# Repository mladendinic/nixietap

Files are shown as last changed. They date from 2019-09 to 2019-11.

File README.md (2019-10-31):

Hello!

You have stumbled upon a repository which contains files for the Nixie Tap device.

What is a Nixie Tap? It's an ESP8266-based Nixie display in a nice enclosure.

By default, it's an internet-synchronized clock, but it could be whatever you desire: IFTTT button, cryptocurrency price ticker, temperature alarm...

To build the latest hardware, use the files from the hardware folder, buy the parts and PCBs, and fire up the soldering iron.

To build the latest firmware, open the 'firmware' repo in VS Code / Github Atom with PlatformIO, and download it to the ESP from there.

There is also a website with more details, here: https://mladendinic.com/nixietap/

Have a nice day!

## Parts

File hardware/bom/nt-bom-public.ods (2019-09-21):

NIXIE TAP REV A BOM
Last modified: 21.09.2019.
Description | Manufacturer 1 | Manufacturer Part Number 1 | Supplier 1 | Supplier Part Number 1 | Quantity
Nixie Tube | NOS | IN-12B | Ebay |  | 4
5K1 1% 0805 | YAGEO | RC0805FR-075K1L | LCSC | C84375 | 1
100K 0805 | YAGEO | RC0805FR-07100KL | LCSC | C96346 | 2
820K 1% 0805 | YAGEO | RC0805JR-07820KL | LCSC | C137403 | 2
10K 0805 | YAGEO | RC0805FR-0710KL | LCSC | C84376 | 9
22K 0805 | YAGEO | RC0805FR-0722KL | LCSC | C114565 | 9
Header, 2 Pin, female | Shenzhen Cankemeng |  | LCSC | C124375 | 1
470pF 50V X7R 10% | YAGEO | CC0805KRX7R9BB471 | LCSC | C107152 | 1
470R 0805 | YAGEO | RC0805FR-07470RL | LCSC | C114564 | 6
SMD Pushbutton 4.5x4.5x7mm | BRIGHT | TSA453G80-250 | LCSC | C294498 | 1
Header, 2 Pin, 90 | Shenzhen Cankemeng |  | LCSC | C124411 | 1
100n 0805 50V | YAGEO | CC0805ZRY5V9BB104 | LCSC | C111496 | 12
Diodes - ESD SOT-23-6 RoHS | STMicroelectronics | USBLC6-2SC6 | LCSC | C7519 | 1
10u 0805 25V | Samsung | CL21A106KAYNNNE | LCSC | C15850 | 4
IC 8BIT SHIFT REG 3ST-OUT 16SOIC | ON Semiconductor | MC74HC595ADR2G | LCSC | C7344 | 1
MLCC - SMD/SMT 500volts .047uF X7R 10% | TDK | C3216X7T2J473KT000N | LCSC | C338056 | 1
Touch Screen Controller ICs SOT-23-6 | Tontek Design Tech | TTP223E-BA6 | LCSC | C129457 | 1
HRO USB micro female vertical TH | Korean Hroparts Elec | U-D-M5DD-W-1 | LCSC | C145795 | 1
XTAL, 12.000MHZ, 16PF, SMD, HC-49S | TXC Corp | 9C12000001 | LCSC | C97206 | 1
MOSFET MOSFT 30V 2.7A 100mOhm 1.0nC | International Rectifier | IRLML2030TRPBF | LCSC | IRLML2030TRPBF | 1
18p 0805 50V | AVX | 08055A180J4T2A | LCSC | C273673 | 3
NCP1117, NCV1117. 1.0 A Low-Dropout Positive | On Semiconductor | NCP1117ST33T3G | LCSC | C26537 | 1
MC306 32.768000KHZ 12.5PF | Seiko Epson | Q13MC3061000300 | LCSC | C16320 | 1
Asynchronous Boost Controller | Feeling Technology | FP5139BWR-LF | LCSC | C88318 | 1
CH340G USB to serial (UART) bridge | Jiangsu Qin Heng | CH340G | LCSC | C14267 | 1
Header, 10 Pin, female | Boom Precision Elec |  | LCSC | C35445 | 7
Header, 10 Pin | Shenzhen Cankemeng |  | LCSC | C124372 | 7
ESP-12F Wi-Fi Module by AI-Thinker | Ai-Thinker | ESP-12F(ESP8266MOD) | LCSC or VITA ELKO | C82891 | 1
1.0 A 600V Ultra Fast Recovery Rectifier | ON Semiconductor / Fairchild | ES1J | LCSC | 512-ES1J | 1
NPN High Voltage Transistor | ON Semiconductor | MMBTA42LT1G | Mouser | 863-MMBTA42LT1G | 6
0.04mm gapped core E13/7/4 N27 LP 0.04MM | EPCOS / TDK | B66305G0040X127 | Mouser | 871-B66305G0040X127 | 2
Bobbin for E13/7/4 ferrite core | EPCOS / TDK | B66306C1010T001 | Mouser | 871-B66306C1010T001 | 1
IC RTC CLK/CALENDAR I2C 8-SOIC | Texas Instruments | BQ32000DR | Mouser | 595-BQ32000DR | 1
Supercap, SMD, 0.2F | Elna | DSK-3R3H224U-HL | Mouser | 555-DSK3R3H224U-HL | 1
IC DISPLAY DVR 20CH 80V 28SOIC | Microchip Technology | HV5812WG-G | Mouser | 689-HV5812WG-G | 2
Header, 10 Pin, female, stackable, 3d model only | CONNFLY | DS1023-05-1*10B8-A16.0/B6.8 | TME | DS1023-05-1X10B816 | 2
PCB |  |  |  |  | 1
PCB | LCSC |  |  |  | 1
PCB |  |  |  |  | 1
PCB | JLCPCB |  |  |  | 1
Nixie pins 50 pack @ 1000pcs |  |  |  |  | 1

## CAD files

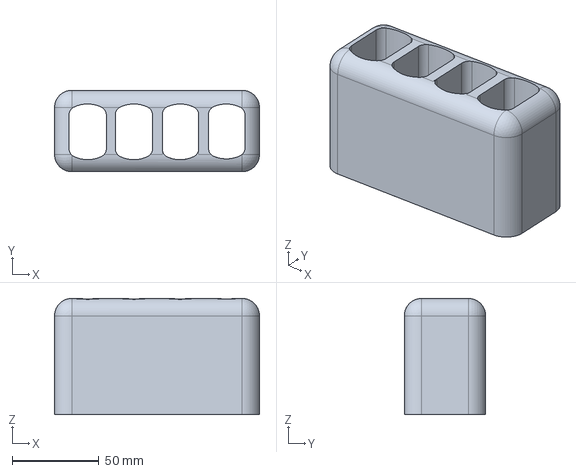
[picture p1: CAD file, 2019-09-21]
hardware/enclosure/nt-enclosure-rev-a.step
118.3 x 47.0 x 67.0 mm

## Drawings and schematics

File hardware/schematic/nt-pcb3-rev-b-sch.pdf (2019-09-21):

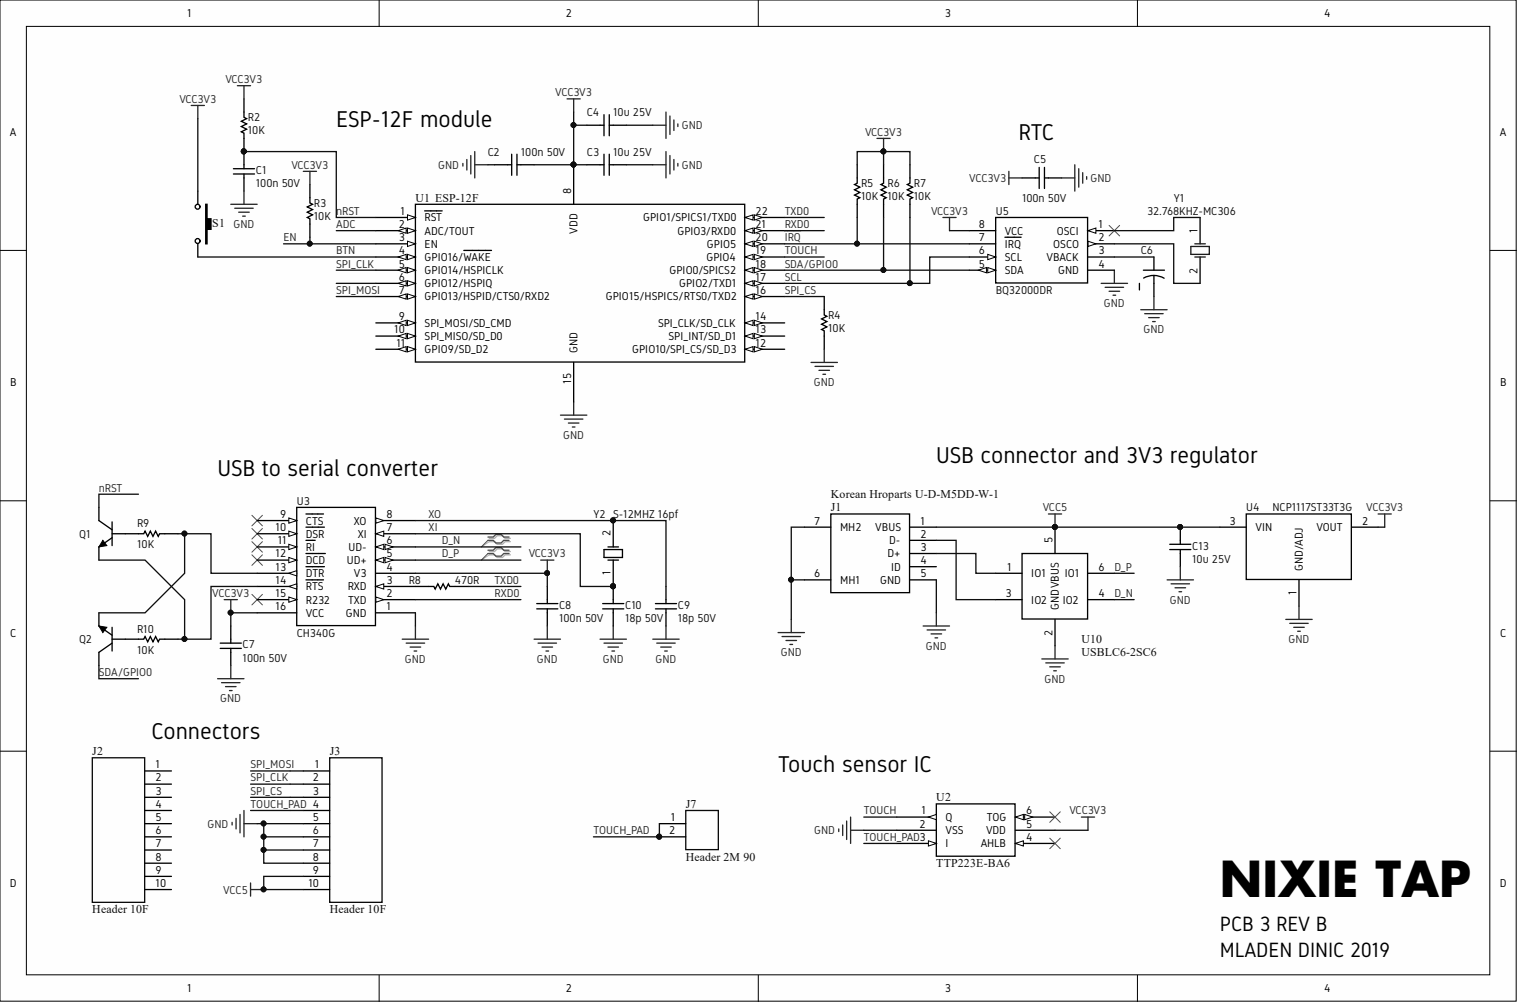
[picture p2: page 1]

GPIO14/HSPICLK 5 GPIO12/HSPIQ 6 GPIO13/HSPID/CTS0/RXD2 7 SPI_MOSI/SD_CMD 9 | SDA/GPIO0

SCL

USB connector and 3V3 regulator USB to serial converter

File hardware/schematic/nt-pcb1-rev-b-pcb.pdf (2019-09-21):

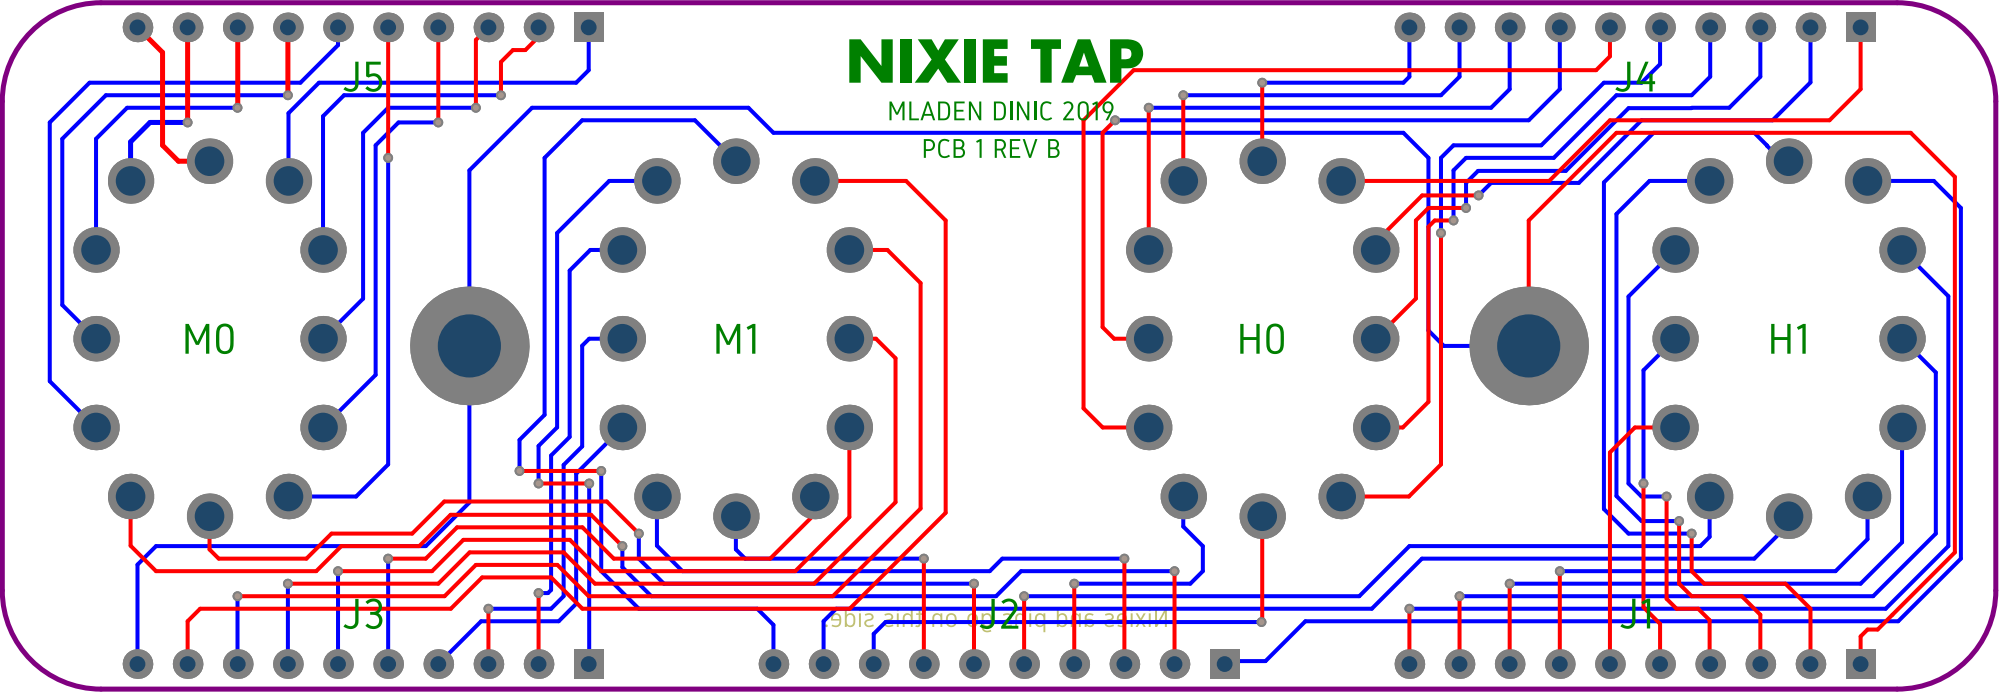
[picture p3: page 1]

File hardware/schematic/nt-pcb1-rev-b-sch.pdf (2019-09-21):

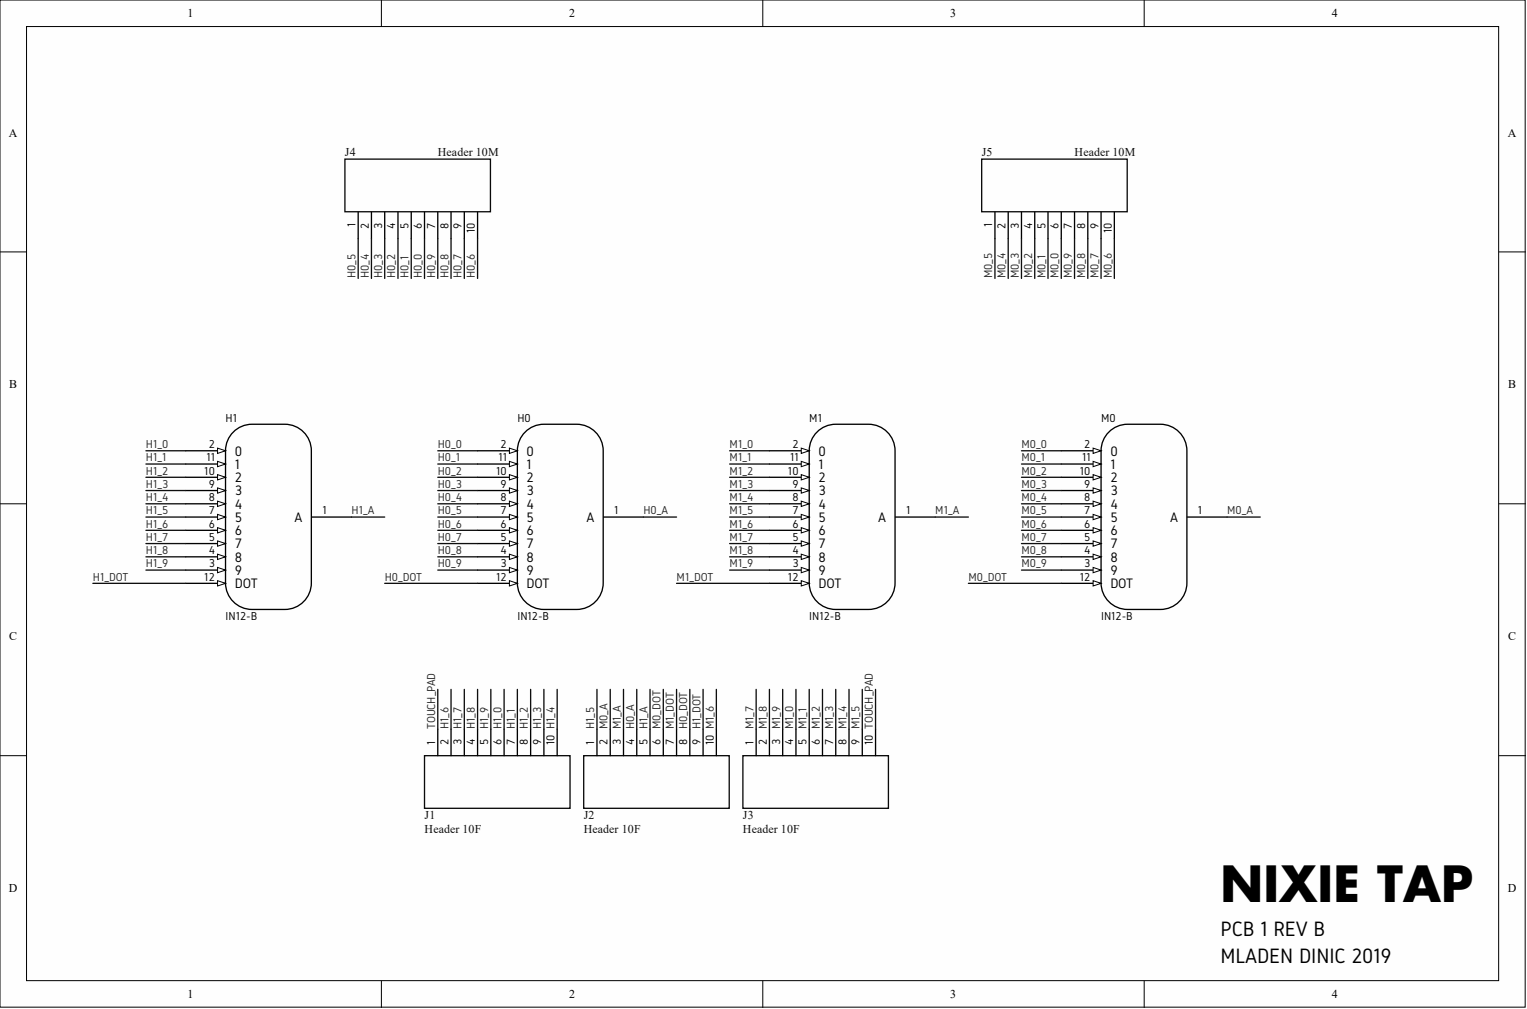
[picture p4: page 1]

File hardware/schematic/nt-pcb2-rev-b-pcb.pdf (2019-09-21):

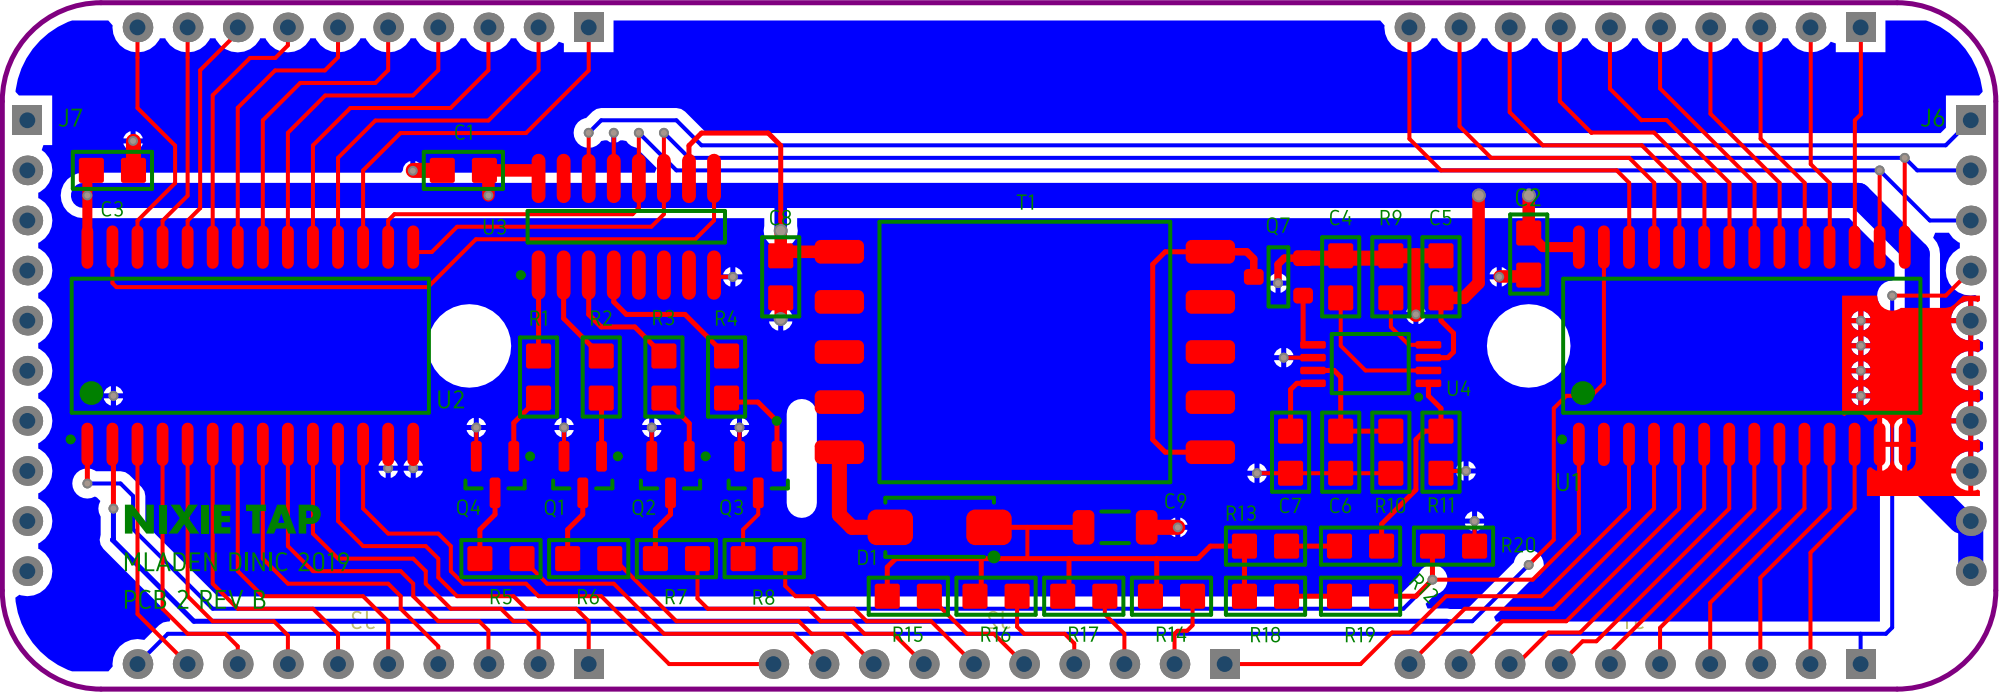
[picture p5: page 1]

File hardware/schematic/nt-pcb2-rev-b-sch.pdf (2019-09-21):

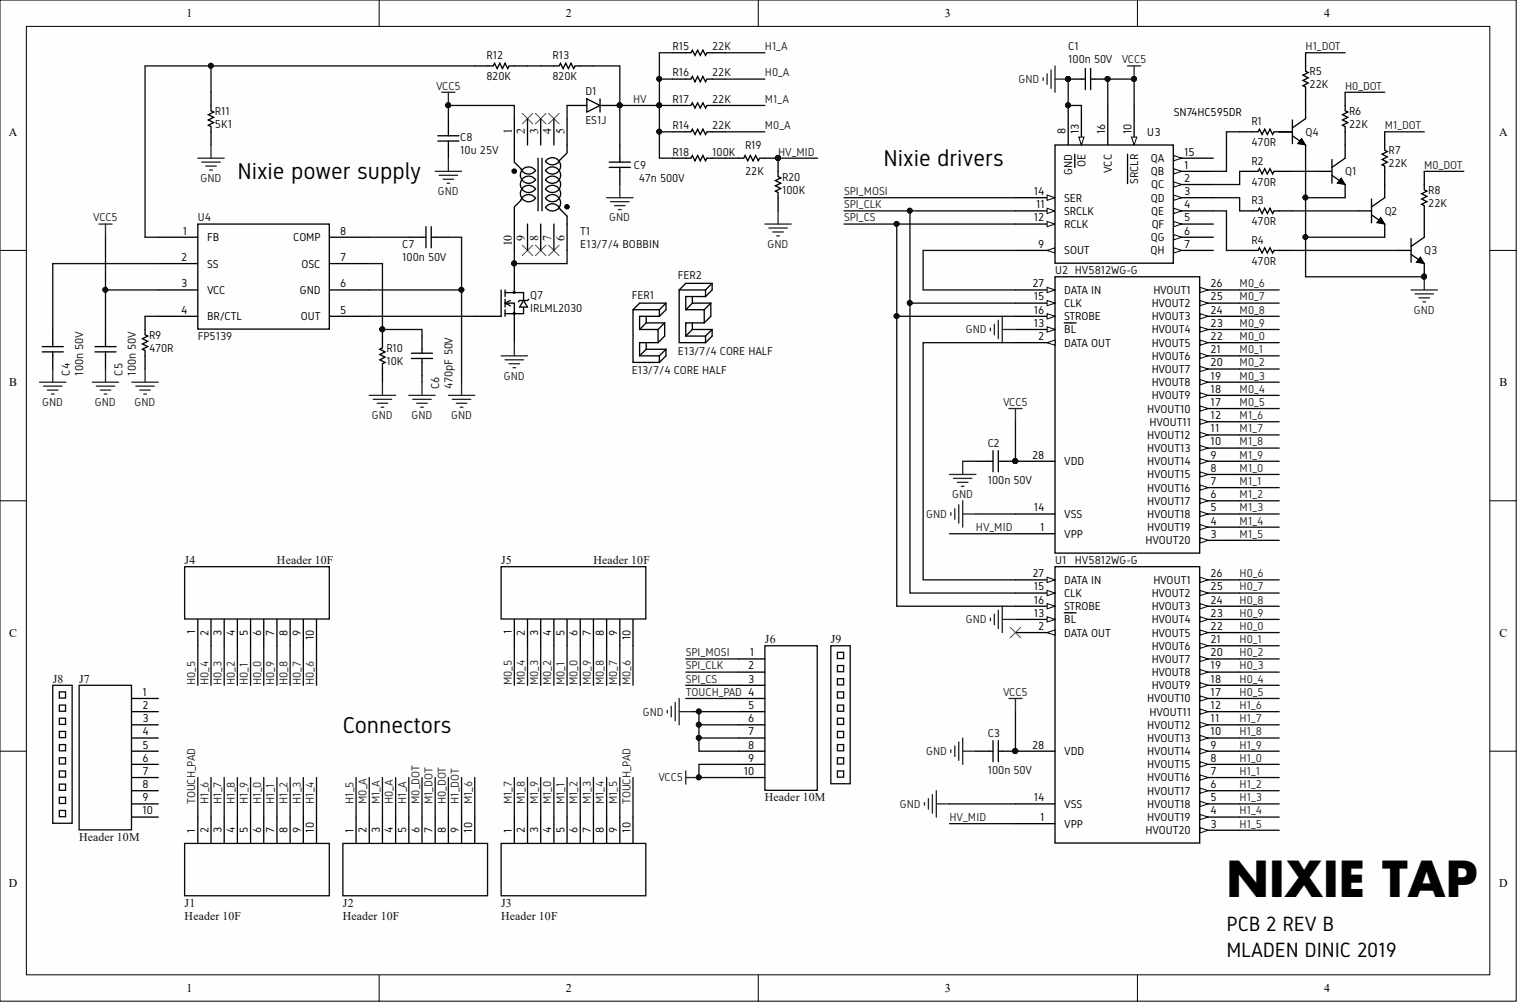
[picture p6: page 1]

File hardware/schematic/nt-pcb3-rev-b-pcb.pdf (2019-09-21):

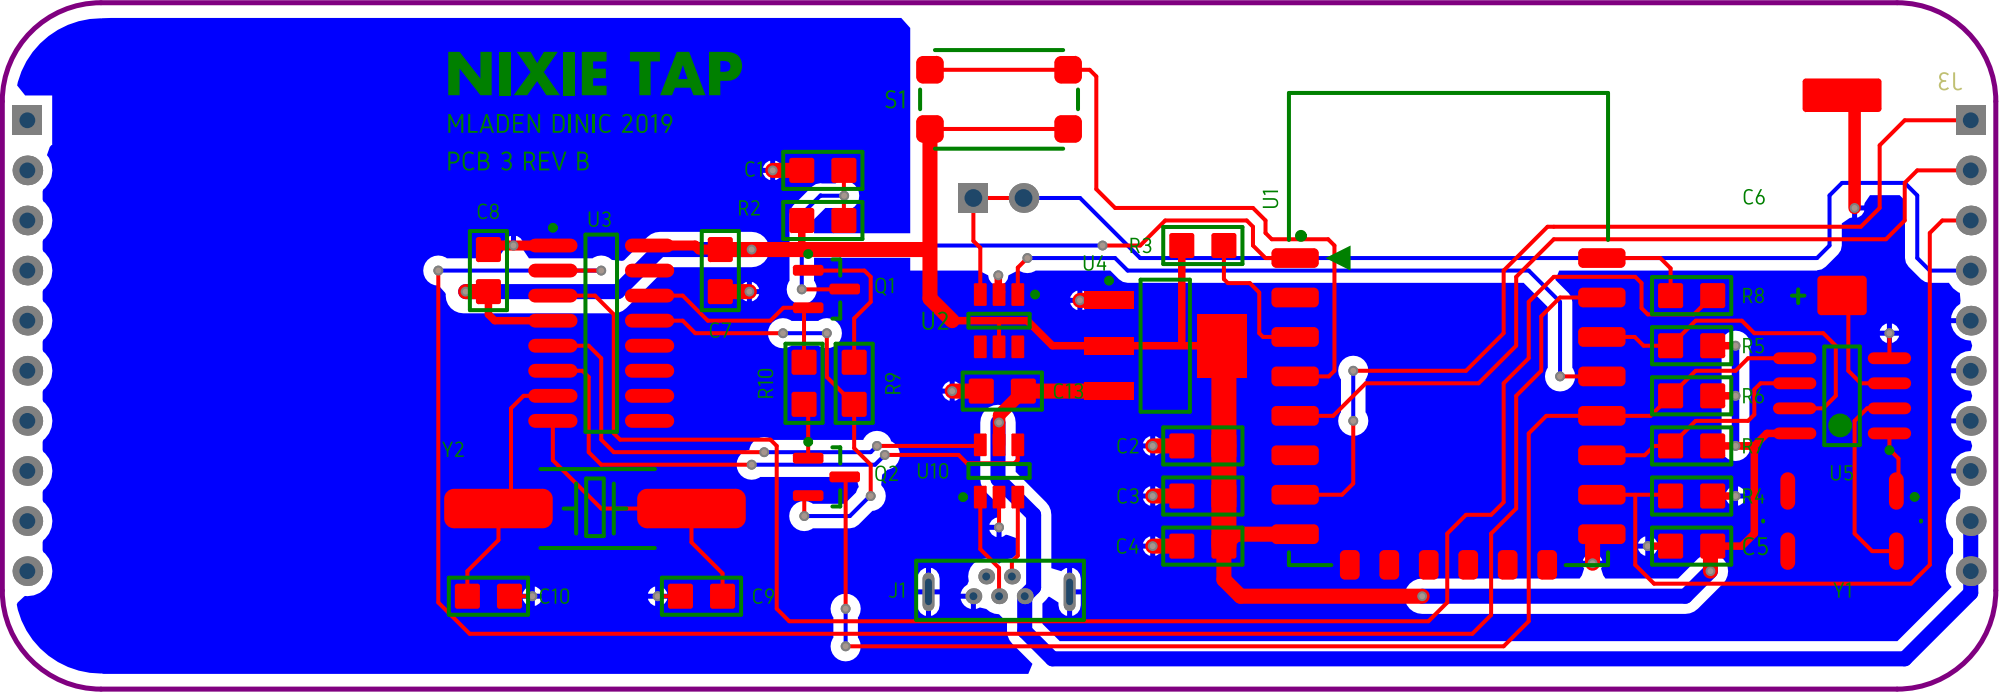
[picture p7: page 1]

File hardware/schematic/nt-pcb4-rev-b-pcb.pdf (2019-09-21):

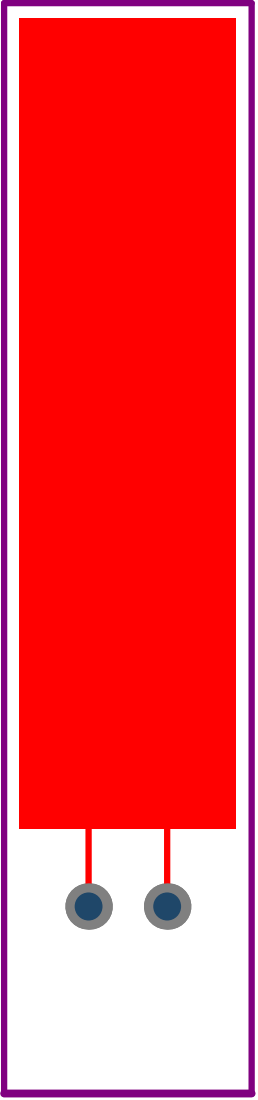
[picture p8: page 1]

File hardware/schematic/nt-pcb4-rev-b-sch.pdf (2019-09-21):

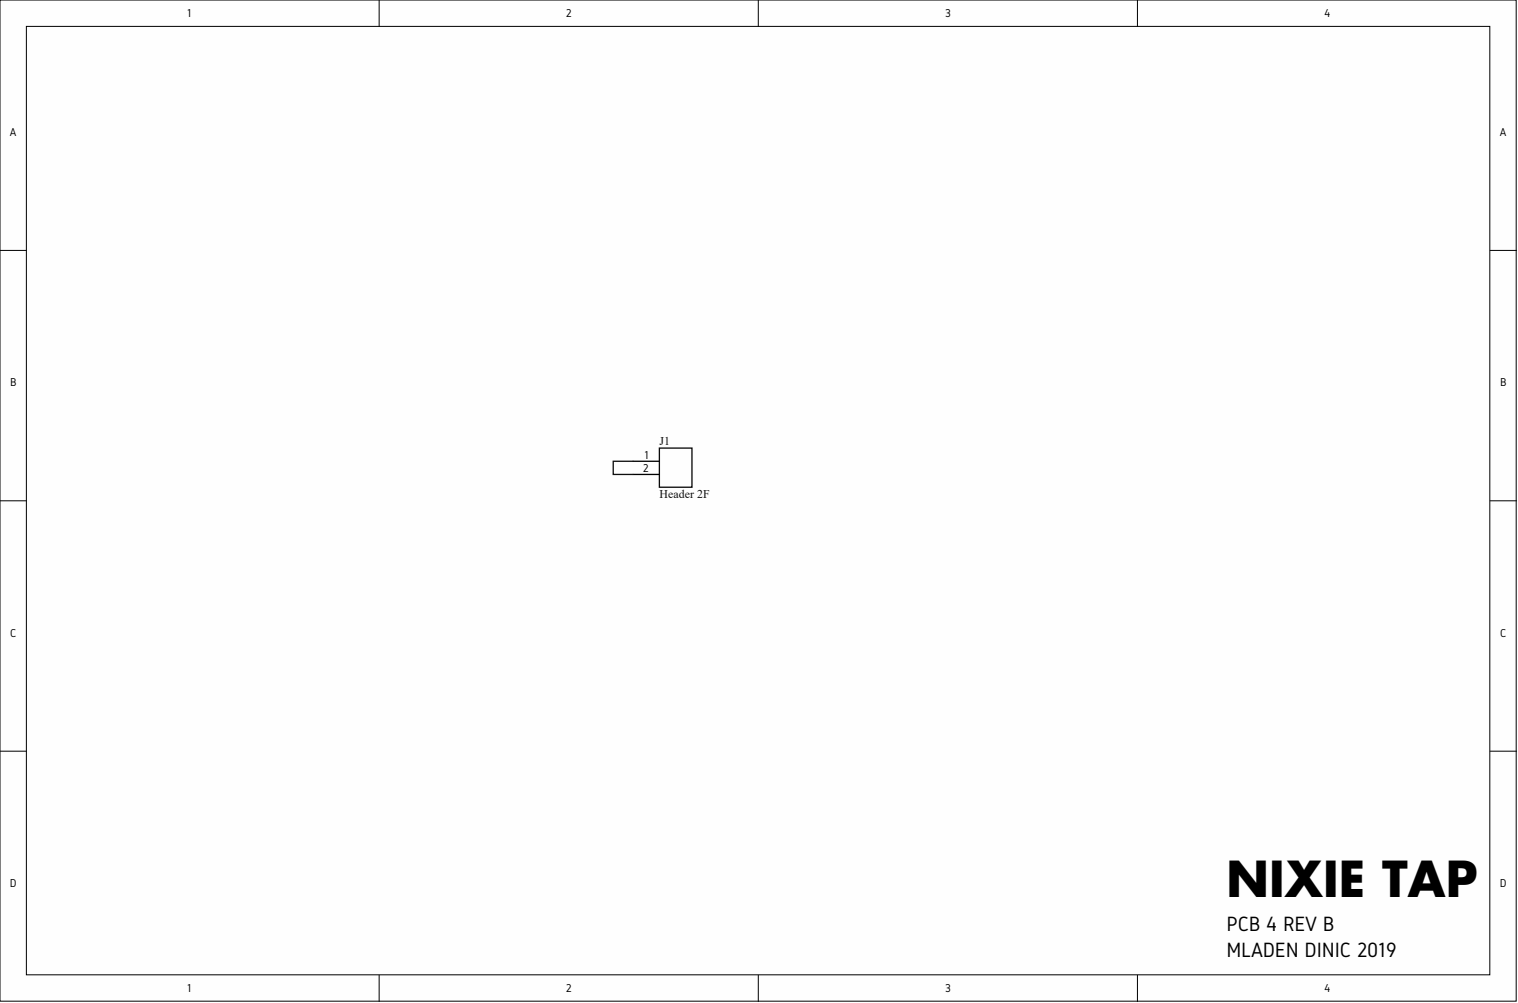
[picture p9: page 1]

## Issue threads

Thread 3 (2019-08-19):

BOM

msurguy, 2019-08-19:
Is there a way to add BOM to this repo?

Also, I'd encourage you to post a license file to clarify how the content in the repo can be used. Thank you!

cpu, 2019-10-17:
> Is there a way to add BOM to this repo?

@msurguy It looks like ab079ec added an ODS formatted BOM to the repository: https://github.com/mladendinic/nixietap/blob/master/hardware/bom/nt-bom-public.ods

> Also, I'd encourage you to post a license file to clarify how the content in the repo can be used. Thank you!

+1

RudolphRiedel, 2020-01-09:
+1 regarding the license.

And as this is supposed to be Open Source Hardware I am missing the Hardware source files.

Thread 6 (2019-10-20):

date is default view

jdonny12, 2019-10-20:
Hi,

I have enabled time and date only.

Date is the default view on on my device and when i tap it shows the time for some seconds. It should be the opposite, time is default. When I tap it should show the date and jump back to date.

Agree?

Thanks,
jd

blendi70, 2019-10-23:
Hi,
same here, enabled date and time only.
After power-up, time is displayed for 10 to 15 minutes then permanetly switches to date. Touch the sensor changes to time for a few seconds, then back to date forever.
The opposite should be default.

Best Regards,
bl

blendi70, 2019-10-28:
Hi,
I think I partially fixed it in HW.
Removed PCB4 and it never switched unintentionally. So sensitivity of touch sensor might be the problem.
The datasheet of tontek sensor says, sensitivity can be adjutsted by adding capacity to pin3 of U2 to GND. I soldered a capacitor 22pF/0402/NP0 between U2/Pin3(TOUCH_PAD) and U2/pin2(GND). Now it does not switch between date and time again, stays in 'time' until you really touch the sensor PCB.
Another thing is, that tontek mentions to keep the tracks to the ic as short as possibe. The net 'TOUCH_PAD' is routed from PCB4 to PCB3, where the touch IC is sitting but it is also spreaded  to PCB2 and PCB1, where it is not needed. I dont know if this was the intention, but this could also be part of the cause.
Best Regards,
bl

mladendinic, 2019-10-28:
Hi!

@blendi70 you're right, the IC is pretty sensitive, and it may pick up switching PSU transformer, which emits noise, which couples to the sensor antenna.
To combat this, the trace connecting the header and PCB1,2 should be cut, as shown on https://mladendinic.com/nixietap/nt-kit.html#5

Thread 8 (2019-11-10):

NixieTap does not boot after flashing firmware 1.1

jdonny12, 2019-11-10:
Hi Mladen,

I wanted to test the new firmware V1.1, but after flashing it my devices does not boot.

It does not shows the running dot and no WiFi is seen. I can not connect to configure it.

Flashing old firmware V1.0 restores function but has the known issue of date default view.

Thanks.

pojzn, 2019-11-10:
Hi there,

what you can try is installing Python on your pc (from python.org), and when it's installed open up a terminal. Type "pip install esptool", and when that finishes type "esptool erase_flash". After this, try uploading V1.1.

Hope this helps

jdonny12, 2019-11-10:
Hi pojzn,

many thanks, that fixed the problem after flashing and the device boots again.

Too bad, the new firmware did not fix the problem of the default date view. I checked the pcb and the wire was already cut on my prebuild device.

jdonny12, 2019-11-10:
Hmm, back on V1.0.

After a power loss device did not boot again and a reset did not activate the access point.

pojzn, 2019-11-10:
I have tried erasing my flash and re-uploading a fresh clone of V1.1 with newly downloaded dependencies, and it seems to work fine, even after rebooting (unplug-plug).

Closed 2019-11-10.

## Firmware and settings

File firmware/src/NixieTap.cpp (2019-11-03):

#include <Arduino.h>
#include <nixie.h>
#include <NixieAPI.h>
#include <BQ32000RTC.h>
#include <NtpClientLib.h> 
#include <TimeLib.h>
#include <WiFiManager.h> 
#include <EEPROM.h>
#include <Ticker.h>
#include <map>

ICACHE_RAM_ATTR void irq_1Hz_int();         // Interrupt function for changing the dot state every 1 second.
ICACHE_RAM_ATTR void touchButtonPressed();   // Interrupt function when button is pressed.
ICACHE_RAM_ATTR void scrollDots();          // Interrupt function for scrolling dots.
void processSyncEvent(NTPSyncEvent_t ntpEvent);
void enableSecDot();
void disableSecDot();
void startPortalManually();    
void updateParameters();
void readParameters();
void cryptoRefresh();
void weatherRefresh();
void updateTime();
void readAndParseSerial();
void resetEepromToDefault(); 
void readButton();
void firstRunInit();

uint8_t fwVersion = 1.1;
volatile bool dot_state = LOW;
bool stopDef = false, secDotDef = false;
bool wifiFirstConnected = true;
bool syncEventTriggered = false; // True if a time event has been triggered.

uint8_t configButton = 0;
volatile uint8_t state = 0, dotPosition = 0b10, weatherRefreshFlag = 1, cryptoRefreshFlag = 1;
char buttonCounter;
uint16_t buttonPressedCounter;
bool buttonPressed = false;
String cryptoCurrencyPrice = "", temperature = "", loc = "";
Ticker movingDot, priceRefresh, temperatureRefresh; // Initializing software timer interrupt called movingDot and priceRefresh.
NTPSyncEvent_t ntpEvent;    // Last triggered event.
WiFiManager wifiManager;
time_t t;
String serialCommand = "";

time_t last_temp;
time_t last_crypto;

uint8 timeRefreshFlag;
uint8 dateRefreshFlag;

char _time[6] = "00:00";
char date[11] = "1970-01-01";
char SSID[50] = "NixieTap";
char password[50] = "nixietap";
char target_SSID[50] = "none";
char target_pw[50] = "none";
uint8 enable_time = 1;
uint8 enable_date = 1;
uint8 enable_crypto = 0;
uint8 enable_temp = 0;
uint8 manual_time_flag = 1;
uint8 enable_DST = 0;
uint8 weather_format = 0;
uint8 enable_24h = 1;
int16_t offset = 0;
char weather_key[50];
char weather_id[50];
char crypto_key[50];
char crypto_id[30];

std::map<String, int> mem_map;


void setup() {
    mem_map["SSID"] = 0;
    mem_map["password"] = 50;
    mem_map["target_ssid"] = 100;
    mem_map["target_pw"] = 150;
    mem_map["weather_key"] = 200;
    mem_map["weather_format"] = 250;
    mem_map["weather_id"] = 251;
    mem_map["crypto_key"] = 302;
    mem_map["crypto_id"] = 351;
    mem_map["manual_time_flag"] = 381;
    mem_map["enable_date"] = 382;
    mem_map["enable_time"] = 383;
    mem_map["enable_temp"] = 384;
    mem_map["enable_crypto"] = 385;
    mem_map["enable_dst"] = 386;
    mem_map["enable_24h"] = 387;
    mem_map["offset"] = 388;
    mem_map["non_init"] = 500;
    // This line prevents the ESP from making spurious WiFi networks (ESP_XXXXX)
	WiFi.mode(WIFI_STA);
	nixieTap.write(10,10,10,10,0b10); // progress bar 25%

    // Touch button interrupt.
    attachInterrupt(digitalPinToInterrupt(TOUCH_BUTTON), touchButtonPressed, RISING);


    if(digitalRead(CONFIG_BUTTON)) {
		delay(5000);
		Serial.println("NIXIE TAP");
		Serial.print("Firmware version: ");
		Serial.println(fwVersion);
	}

	nixieTap.write(10,10,10,10,0b110); // progress bar 50%

	firstRunInit(); 
    readParameters();           // Read all stored parameters from EEPROM.

	nixieTap.write(10,10,10,10,0b1110); // progress bar 75%

    setSyncProvider(RTC.get);   // the function to get the time from the RTC
    enableSecDot();
	// Serial debug message
	if(timeStatus()!= timeSet)
		Serial.println("Unable to sync with the RTC!");
	else
		Serial.println("RTC has set the system time!");
	
	nixieTap.write(10,10,10,10,0b11110); // progress bar 100%
}
void loop() {
	// Polling functions
	readAndParseSerial();
	readButton();

	// Mandatory functions to be executed every cycle
    t = now(); // update date and time variable

    // If time is configured to be set semi-auto or auto and NixiTap is just started, the NTP request is created.
    if(manual_time_flag == 0 && wifiFirstConnected && WiFi.status() == WL_CONNECTED) {
        NTP.onNTPSyncEvent([](NTPSyncEvent_t event) {ntpEvent = event; syncEventTriggered = true;});
        NTP.begin();
        wifiFirstConnected = false;
    }
    if(syncEventTriggered) {
        processSyncEvent(ntpEvent);
        syncEventTriggered = false;
    }
    
	// State machine
    if(state > 3) state = 0;

	// Slot 0 - time
    if(state == 0 && enable_time) {
        nixieTap.writeTime(t, dot_state, enable_24h);
    } 
	else if(!enable_time && state == 0) state++;

	// Slot 1 - date 
	if(state == 1 && enable_date) {
		nixieTap.writeDate(t, 1);
	} 
	else if(!enable_date && state == 1) state++;

	// Slot 2 - crypto price
	if(state == 2 && enable_crypto) {
        if(cryptoRefreshFlag) {
            cryptoRefreshFlag = 0;
            cryptoCurrencyPrice = nixieTapAPI.getCryptoPrice(crypto_key, crypto_id);
            last_crypto = now();
        }
        if (now() - last_crypto >= 60){
            cryptoRefreshFlag = 1;
        }
        nixieTap.writeNumber(cryptoCurrencyPrice, 250);
	}
	else if(!enable_crypto && state == 2) state++;
	
	// Slot 3 - temperature
	if(state == 3 && enable_temp) {
		if(weather_key[0] != '\0') {
			if(weatherRefreshFlag) {
				weatherRefreshFlag = 0;
                temperature = nixieTapAPI.getTempAtMyLocation(weather_id, weather_format);
                last_temp = now();
			}
            // Checking local temp every 5 minutes
            if (now() - last_temp >= 300){ 
                weatherRefreshFlag = 1;
            }
			nixieTap.writeNumber(temperature, 0);
		} else state++;
	}
	else if(!enable_temp && state == 3) state++;

    // Here you can add new functions for displaying numbers on NixieTap, just follow the basic writing principle from above.
}

void startPortalManually() {
    // By pressing the button on the back of the device you can manually start the WiFi Manager and access it's settings.
    nixieTap.write(10, 10, 10, 10, 0);
    disableSecDot(); // If the dots are not disabled, precisely the RTC_IRQ_PIN interrupt, ConfigPortal will chrach.
    movingDot.attach(0.2, scrollDots);
	Serial.println("---------------------------------------------------------------------------------------------");
    wifiManager.setConfigPortalTimeout(1800);
    // This will run a new config portal if the SSID and PW are valid.
    if(!wifiManager.startConfigPortal(SSID, password)) {
		Serial.println("Failed to connect and hit timeout!");
        // If the NixieTap is not connected to WiFi, it will collect the entered parameters and configure the RTC according to them.
    }
    updateParameters();
    updateTime();
    movingDot.detach();
    nixieTap.write(10, 10, 10, 10, 0); // Deletes remaining dot on display.
    enableSecDot();
}

void processSyncEvent(NTPSyncEvent_t ntpEvent) {
	Serial.println("---------------------------------------------------------------------------------------------");
	// When syncEventTriggered is triggered, through NTPClient, Nixie checks if NTP time is received.
    // If NTP time is received, Nixie starts synchronization of RTC time with received NTP time and stops NTPClinet from sending new requests.

        if(ntpEvent < 0) {
			Serial.print("Time Sync error: ");
			if(ntpEvent == noResponse) {
				Serial.println("NTP server not reachable.");
			} else if(ntpEvent == invalidAddress) {
				Serial.println("Invalid NTP server address.");
			} else if (ntpEvent == errorSending) {
				Serial.println ("Error sending request");
			} else if (ntpEvent == responseError) {
				Serial.println ("NTP response error");
			}
			Serial.println("Synchronization will be attempted again after 15 seconds.");
			Serial.println("If the time is not synced after 2 minutes, please restart Nixie Tap and try again!");
			Serial.println("If restart does not help. There might be a problem with the NTP server or your WiFi connection. You can set the time manually.");
        } else {
            if(NTP.getLastNTPSync() != 0) {
				Serial.print("NTP time is obtained: ");
				Serial.println(NTP.getLastNTPSync());
                if(!manual_time_flag) {
					Serial.println("Auto time adjustment started!");
                    // Collect NTP time, put it in RTC and stop NTP synchronization.
                    RTC.set(NTP.getLastNTPSync() + offset*60 + enable_DST*60*60);
                    NTP.stop();
                    setSyncProvider(RTC.get);
                    wifiFirstConnected = false;
                }
            }
        }
}
void readParameters() {
	Serial.println("Reading saved parameters from EEPROM.");
    int EEaddress = mem_map["SSID"];
    EEPROM.get(EEaddress, SSID);
    Serial.println("SSID IS:"+(String)SSID);
    EEaddress = mem_map["password"];
    EEPROM.get(EEaddress, password);
    Serial.println("PW IS:" + (String)password);
    EEaddress = mem_map["target_ssid"];
    EEPROM.get(EEaddress, target_SSID);
    Serial.println("Target SSID IS:" + (String)target_SSID);
    EEaddress = mem_map["target_pw"];
    EEPROM.get(EEaddress, target_pw);
    Serial.println("Target PW IS:" + (String)target_pw);
    EEaddress = mem_map["weather_key"];
    EEPROM.get(EEaddress, weather_key);
    Serial.println("WEATHER KEY IS:" + (String)weather_key);
    EEaddress = mem_map["weather_id"];
    EEPROM.get(EEaddress, weather_id);
    Serial.println("WEATHER ID IS:" + (String)weather_id);
    EEaddress = mem_map["weather_format"];
    EEPROM.get(EEaddress, weather_format);
    Serial.println("WEATHER FORMAT IS:" + (String)weather_format);
    EEaddress = mem_map["crypto_key"];
    EEPROM.get(EEaddress, crypto_key);
    Serial.println("CRYPTO KEY IS:" + (String)crypto_key);
    EEaddress = mem_map["crypto_id"];
    EEPROM.get(EEaddress, crypto_id);
    Serial.println("CRYPTO ID IS:" + (String)crypto_id);
    EEaddress = mem_map["manual_time_flag"];
    EEPROM.get(EEaddress, manual_time_flag);
    Serial.println("MANUAL TIME FLAG IS:" + (String)manual_time_flag);
    EEaddress = mem_map["enable_date"];
    EEPROM.get(EEaddress, enable_date);
    Serial.println("ENABLE DATE IS:" + (String)enable_date);
    EEaddress = mem_map["enable_time"];
    EEPROM.get(EEaddress, enable_time);
    Serial.println("ENABLE TIME IS:" + (String)enable_time);
    EEaddress = mem_map["enable_24h"];
    EEPROM.get(EEaddress, enable_24h);
    Serial.println("24H IS:" + (String)enable_24h);
    EEaddress = mem_map["enable_temp"];
    EEPROM.get(EEaddress, enable_temp);
    Serial.println("ENABLE TEMP IS:" + (String)enable_temp);
    EEaddress = mem_map["enable_crypto"];
    EEPROM.get(EEaddress, enable_crypto);
    Serial.println("ENABLE CRYPTO IS:" + (String)enable_crypto);
    EEaddress = mem_map["enable_dst"];
    EEPROM.get(EEaddress, enable_DST);
    Serial.println("ENABLE DST IS:" + (String)enable_DST);
    EEaddress = mem_map["offset"];
    EEPROM.get(EEaddress, offset);
    Serial.println("OFFSET IS:" + (String)offset);

    nixieTapAPI.applyKey(weather_key, 4);
}

void updateParameters() {
	Serial.println("---------------------------------------------------------------------------------------------");
	Serial.println("Synchronization of parameters started.");
    EEPROM.begin(512); // Number of bytes to allocate for parameters.
    int EEaddress;
    Serial.println("Comparing entered keys with the saved ones.");
    if (wifiManager.nixie_params.count("SSID") == 1){
        const char * nixie_ssid = wifiManager.nixie_params["SSID"].c_str();
        if (nixie_ssid != "\0" and SSID != nixie_ssid)
        {
            EEaddress = mem_map["SSID"];
            strcpy(SSID, nixie_ssid);
            EEPROM.put(EEaddress, SSID);   
            const char * nixie_pw = wifiManager.nixie_params["hotspot_password"].c_str();
            if (nixie_pw != "\0" and password != nixie_pw)
            {
                EEaddress = mem_map["password"];
                strcpy(password, nixie_pw);
                EEPROM.put(EEaddress, password);
            }
        }
    }
    if (wifiManager.nixie_params.count("target_ssid") == 1){
        const char * new_target_ssid = wifiManager.nixie_params["target_ssid"].c_str();
        if (new_target_ssid != "\0" and target_SSID != new_target_ssid)
        {
            EEaddress = mem_map["target_ssid"];
            strcpy(target_SSID, new_target_ssid);
            EEPROM.put(EEaddress, target_SSID);
            const char * new_target_pw = wifiManager.nixie_params["target_password"].c_str();
            if (new_target_pw != "\0" and new_target_pw != target_pw)
            {
                EEaddress = mem_map["target_pw"];
                strcpy(target_pw, new_target_pw);
                EEPROM.put(EEaddress, target_pw);
                wifiManager.connectWifi(target_SSID, target_pw);
            }
        }
    }
    if (wifiManager.nixie_params.count("weather_api") == 1)
    {
        const char *new_weather_key = wifiManager.nixie_params["weather_api"].c_str();
        if (new_weather_key != "\0" and new_weather_key != weather_key)
        {
            EEaddress = mem_map["weather_key"];
            strcpy(weather_key, new_weather_key);
            EEPROM.put(EEaddress, weather_key);
            nixieTapAPI.applyKey(weather_key, 4);
            weatherRefreshFlag = 1;
        }
    }
    if (wifiManager.nixie_params.count("weather_id") == 1)
    {
        const char *new_weather_id = wifiManager.nixie_params["weather_id"].c_str();
        if (new_weather_id != "\0" and new_weather_id != weather_id)
        {
            EEaddress = mem_map["weather_id"];
            strcpy(weather_id, new_weather_id);
            EEPROM.put(EEaddress, weather_id);
            weatherRefreshFlag = 1;
        }
    }
    if (wifiManager.nixie_params.count("weatherFormat") == 1)
    {
        uint8_t user_input_weather_format = atoi(wifiManager.nixie_params["weatherFormat"].c_str());
        if (user_input_weather_format != weather_format)
        {
            weather_format = user_input_weather_format;
            EEaddress = mem_map["weather_format"];
            EEPROM.put(EEaddress, weather_format);
            weatherRefreshFlag = 1;
        }
    }
   
    if (wifiManager.nixie_params.count("cryptoID") == 1)
    {
        const char *new_crypto_id = wifiManager.nixie_params["cryptoID"].c_str();
        if (new_crypto_id != "\0" and new_crypto_id != crypto_id)
        {
            EEaddress = mem_map["crypto_id"];
            strcpy(crypto_id, new_crypto_id);
            EEPROM.put(EEaddress, crypto_id);
        }
    }
    uint8_t new_enable_date = (uint8_t)wifiManager.nixie_params.count("enableDate");
    if (new_enable_date != enable_date){
        EEaddress = mem_map["enable_date"];
        enable_date = new_enable_date;
        EEPROM.put(EEaddress, enable_date);
    }
    uint8_t new_enable_time = (uint8_t)wifiManager.nixie_params.count("enableTime");
    if (new_enable_time != enable_time)
    {
        EEaddress = mem_map["enable_time"];
        enable_time = new_enable_time;
        EEPROM.put(EEaddress, new_enable_time);
    }
    uint8_t new_enable_24h = (uint8_t)wifiManager.nixie_params.count("enable24h");
    if (enable_24h != new_enable_24h)
    {
        EEaddress = mem_map["enable_24h"];
        enable_24h = new_enable_24h;
        EEPROM.put(EEaddress, enable_24h);
    }
    uint8_t new_enable_temp = (uint8_t)wifiManager.nixie_params.count("enableTemp");
    if (new_enable_temp != enable_temp)
    {
        EEaddress = mem_map["enable_temp"];
        enable_temp = new_enable_temp;
        EEPROM.put(EEaddress, enable_temp);
    }
    uint8_t new_enable_crypto = (uint8_t)wifiManager.nixie_params.count("enableCrypto");
    if (new_enable_crypto != enable_crypto)
    {
        EEaddress = mem_map["enable_crypto"];
        enable_crypto = new_enable_crypto;
        EEPROM.put(EEaddress, enable_crypto);
    }
    uint8_t new_enable_dst = (uint8_t)wifiManager.nixie_params.count("dst");
    if (new_enable_dst != enable_DST)
    {
        EEaddress = mem_map["enable_dst"];
        enable_DST = new_enable_dst;
        EEPROM.put(EEaddress, enable_DST);
    }
    if (wifiManager.nixie_params.count("setTimeManuallyFlag") == 1)
    {
        uint8_t new_manual_time_flag = atoi(wifiManager.nixie_params["setTimeManuallyFlag"].c_str());
        if (new_manual_time_flag != manual_time_flag){
            EEaddress = mem_map["manual_time_flag"];
            uint8_t temp_time_flag = new_manual_time_flag;
            EEPROM.put(EEaddress, temp_time_flag);
        }
        manual_time_flag = new_manual_time_flag;
        timeRefreshFlag = 1;
    }
    if (wifiManager.nixie_params.count("offset") == 1)
    {
        int16_t new_offset = atoi(wifiManager.nixie_params["offset"].c_str());
        if (new_offset != offset){
            EEaddress = mem_map["offset"];
            offset = new_offset;
            EEPROM.put(EEaddress, offset);
        }
    }
    if (wifiManager.nixie_params.count("time") == 1)
    {
        const char * new_time = wifiManager.nixie_params["time"].c_str();
        if (new_time != "\0" and new_time != _time)
        {
            strcpy(_time, new_time);
            timeRefreshFlag = 1;
        }
    }
    if (wifiManager.nixie_params.count("date") == 1)
    {
        const char * new_date = wifiManager.nixie_params["date"].c_str();
        if (new_date != "\0" and new_date != date)
        {
            strcpy(date, new_date);
            timeRefreshFlag = 1;
        }
    }

    if (wifiManager.nixie_params.count("stackKey") == 1)
    {
        const char *new_crypto_key = wifiManager.nixie_params["stackKey"].c_str();
        if (new_crypto_key != "\0" and new_crypto_key != crypto_key)
        {
            EEaddress = mem_map["crypto_key"];
            strcpy(crypto_key, new_crypto_key);
            EEPROM.put(EEaddress, crypto_key);
        }
    }
    // Setting the "non initialized" flag to 0
    EEaddress = mem_map["non_init"];
    EEPROM.put(EEaddress, 0);

    EEPROM.commit();
    if(enable_crypto) {
        priceRefresh.attach(300, cryptoRefresh); // This will refresh the cryptocurrency price every 5min.
    } else 
        priceRefresh.detach();
    if(enable_temp) {
        temperatureRefresh.attach(3600, weatherRefresh);
    } else
        temperatureRefresh.detach();
    wifiManager.nixie_params.clear();
    Serial.println("Synchronization of parameters completed!");
}

void updateTime() {
    if (timeRefreshFlag){
        if(manual_time_flag) { // I need feedback from the WiFiManager API that this option has been selected.
            NTP.stop();     // NTP sync is disableded to avoid sync errors.
            int hours = -1;
            int minutes = -1;
            char * time_token = strtok(_time, ":");
            while (time_token != NULL)
            {
                if(hours == -1){
                    hours = atoi(time_token);
                }else{
                    minutes = atoi(time_token);
                }
                time_token = strtok(NULL, " ");
            }
            int year = -1;
            int month = -1;
            int day = -1;
            char * date_token = strtok(date, "-");
            while (date_token != NULL)
            {
                if(year == -1){
                    year = atoi(date_token);
                }
                else if (month == -1){
                    month = atoi(date_token);
                }else{
                    day = atoi(date_token);
                }
                date_token = strtok(NULL, "-");
            }
            setTime(hours, minutes, 0, day, month, year);
            t = now();
            RTC.set(t);
            setSyncProvider(RTC.get);
            Serial.println("Manually entered date and time saved!");
        }else if (WiFi.status() == WL_CONNECTED){
            Serial.println("NixieTap is auto and connected, setting time to NTP!");
            NTP.onNTPSyncEvent([](NTPSyncEvent_t event) {ntpEvent = event; syncEventTriggered = true;});
            NTP.begin();
            wifiFirstConnected = false;
        }else{
            Serial.println("NixieTap not connected to WiFi, cannot auto sync time via NTP!");
        }
        timeRefreshFlag = 0;
    }
}

/*                                                           *
 *  Enables the center dot to change its state every second. *
 *                                                           */
void enableSecDot() {
    if(secDotDef == false) {
        detachInterrupt(RTC_IRQ_PIN);
        RTC.setIRQ(1);  // Configures the 512Hz interrupt from RTC.
        attachInterrupt(digitalPinToInterrupt(RTC_IRQ_PIN), irq_1Hz_int, FALLING);
        secDotDef = true;
        stopDef = false;
    }
}
/*                                                *
 * Disaling the dots function on nixie display.   *
 *                                                */
void disableSecDot() {
    if(stopDef == false) {
        detachInterrupt(RTC_IRQ_PIN);
        RTC.setIRQ(0);              // Configures the interrupt from RTC.
        dotPosition = 0b10;         // Restast dot position.
        stopDef = true;
        secDotDef = false;
    }
}
/*                                                                                       *
 * An interrupt function that changes the state and position of the dots on the display. *
 *                                                                                       */
void scrollDots() {
    if(dotPosition == 0b100000) dotPosition = 0b10;
    nixieTap.write(11, 11, 11, 11, dotPosition);
    dotPosition = dotPosition << 1;
}
/*                                                                  *
 * An interrupt function for changing the dot state every 1 second. *
 *                                                                  */
void irq_1Hz_int() {
    dot_state = !dot_state;
}
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

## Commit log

2017-09-28 Simple network clock, working on PCB1.1 revision
2017-10-03 Software is now interrupt driven, via 1Hz squarewave from BQ32000
2017-10-15 Added gerber files for 1.1 version
2017-12-23 RTC is now working. Time is displayed on nixies. 1Hz interrupt from rtc now works. Trickle charge is now enabled.
2018-02-19 Scrolling dots are now controled with an external 512Hz RTC interrupt. Also WiFiManager portal can now be called manually bay taping NixieTap 5 times(in a time gape of a 800ms).
2018-04-27 Manual time configuration mode enabled, Created new NixieAPI library for Time API, Location API, etc... Minor bugs are corrected.
    [NixieTap.cpp]
2018-05-04 Automatically adjust the time and date for the detected location is fully operational. The API library offers 4 API services for providing location and time zone parameters, including 2 APIs for a pu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
    [NixieTap.cpp]
2018-05-13 Solved problem with scrolling dots.
    [NixieTap.cpp]
2018-05-24 Interrupt now on rising edge; minor code changes
2018-05-30 The cryptocurrency function has been redesigned. It is now possible to choose, from the WiFiManager AP, which cryptocurrency price will be displayed on the nixie tubes. Also some minor corrections in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
    [NixieTap.cpp]
2018-06-02 Added gerbers and schematic rev-a
2018-06-07 Some bugs are fixed. Added a new function for weather, you can now get the current temperature for your location.
    [NixieTap.cpp]
2018-06-07 changed to lowercase, to fix Linux compile issue
    [NixieTap.cpp]
2018-06-14 Corrected sync problem with a currency and the weather. NixieTap now calls the API service for the time zone depending on which API keys are entered. Changed the type of timeZone and minutes TimeZone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
    [NixieTap.cpp]
2018-07-08 Added mechanical files
    [Nixie Tap v5.step]
2018-09-18 Temporarely disabled temperature display
2018-12-09 Added version B pcb and sch, pdf version
2018-12-09 Added Gerber files version B, deleted Gerber files version A
2019-07-15 Button now changes state. Press and hold to go into Portal mode.
2019-09-21 Deleted old files
    [Nixie Tap v5.step]
2019-09-21 Added production files
    [nt-bom-public.ods, nt-enclosure-rev-a.step]
2019-10-17 README: Remove broken enclosure image embed.
    Similar to the `nixie-tap.gif` the `IMG_7451.JPG` image was removed in
    was removed in 67cb834 leading to a broken image embed in the HTML
    rendering of the Github README.
    There are two new photos in `hardware/photos` but they are both large
    (~3 to ~5mb) and neither show off the hardware enclosure and so didn't
    seem like appropriate replacements.
2019-10-18 firmware: fix "temerature" typo in web config UI.
    [NixieTap.cpp]
2019-10-31 Updated NixieTap.cpp and NixieTapAPI. Crypto still doesn't work.
    [NixieTap.cpp]
